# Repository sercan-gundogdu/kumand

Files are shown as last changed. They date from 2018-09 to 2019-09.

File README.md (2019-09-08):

# kumand [discontinued*]
Kumand is a low-power user-configurable remote controller device for personal computers, working on WLAN, allowing to manipulate every single media tool that has functionality to operate with keyboard shortcuts/hotkeys by emulating keystrokes determined in selected profile.

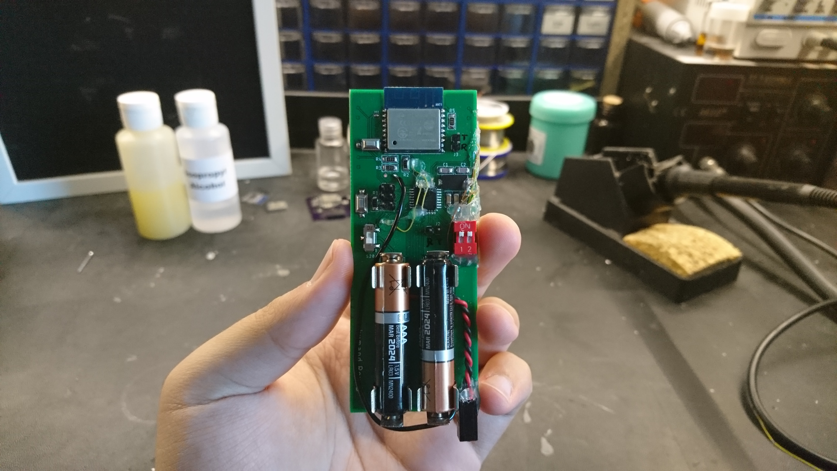
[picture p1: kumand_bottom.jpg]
kumand bottom

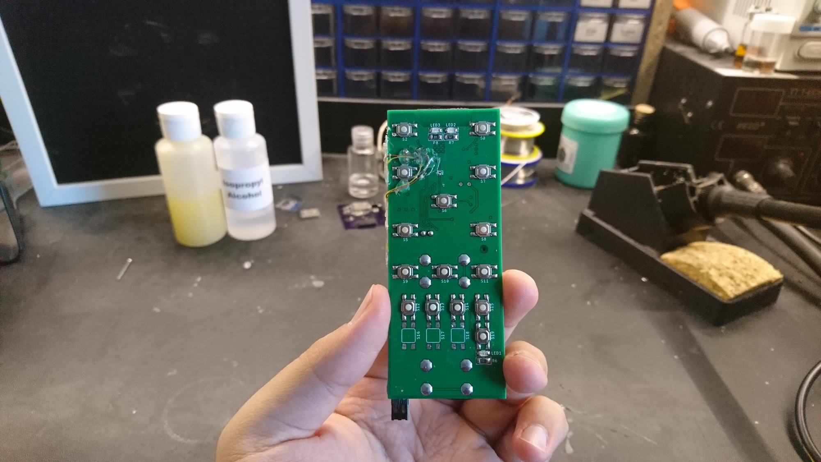
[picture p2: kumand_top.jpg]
kumand top


*The project is discontinued because the ESP8266 SoC does not meet the project's requirements in the aspect of power consumption and connectivity speed, it seems that ESP8266 has no proper sleep functionality to implement. The project will be redesigned with appropriate connectivity IC and MCU.

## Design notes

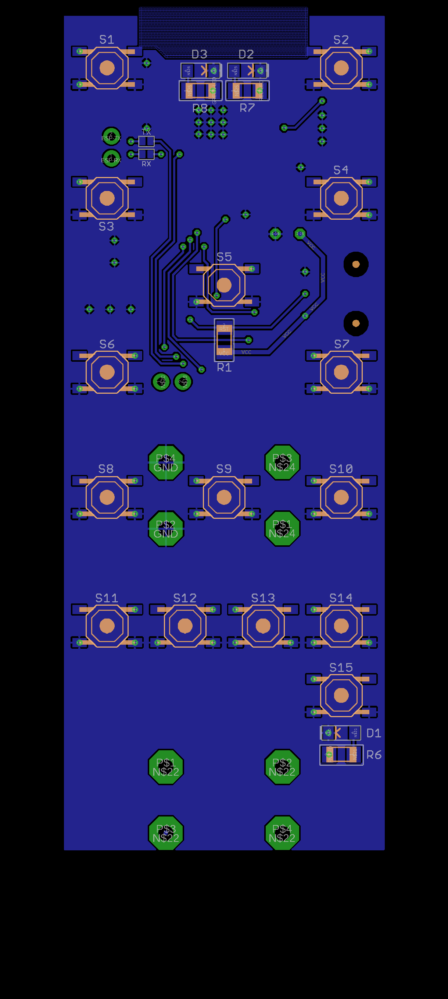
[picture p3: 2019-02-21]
source/hardware/pcb/bottom.png

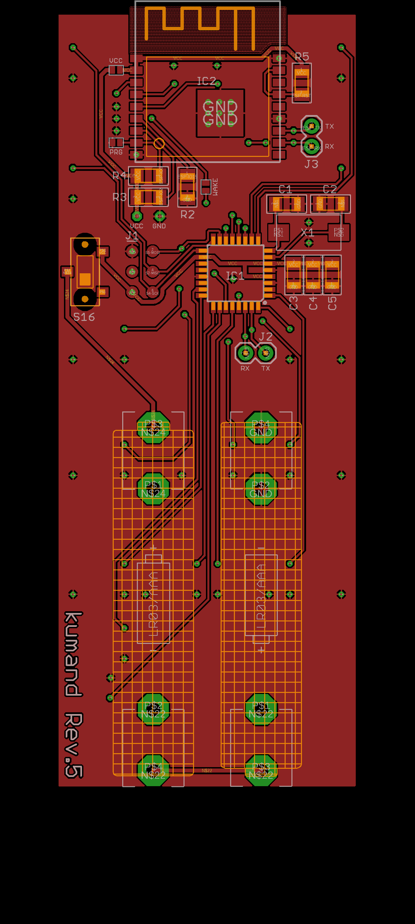
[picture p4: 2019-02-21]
source/hardware/pcb/top.png

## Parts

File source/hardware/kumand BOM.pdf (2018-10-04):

# | Designator | Manufacturer | Manufacturer PN | Value | Parametrics | Package | Layer

1 IC1 | Microchip Technology | ATMEGA328P-AUR | 1 | - | | TQFP | SMD | TOP
2 IC2 | Espressif Systems | ESP-WROOM-02 | 1 | - | | - | SMD | TOP
3 X1 | NDK America, Inc. | NX8045GB | 1 | 7.3728 MHz | | 8045[3117] | SMD | TOP
4 R1:R5 | Panasonic Electronic Components | ERJ-P08J103V | 5 | 10k Ohms | -55°C ~ +155°C, ±5%, 0.667W, 2/3W | | SMD | TOP
5 R6 | Panasonic Electronic Components | ERJ-8GEYJ101V | 1 | 100 Ohms | -55°C ~ +155°C, ±5%, 0.25W, 1/4W | | SMD | BOTTOM
6 R7 | Panasonic Electronic Components | ERJ-8GEYJ221V | 1 | 220 Ohms | -55°C ~ +155°C, ±5%, 0.25W, 1/4W | | SMD | BOTTOM
7 R8 | Panasonic Electronic Components | ERJ-8GEYJ561V | 1 | 480 Ohms | -55°C ~ +155°C, ±5%, 0.25W, 1/4W | | SMD | BOTTOM
8 C1,C2 | Samsung Electro-Mechanics | CL31C100DBCNNNC | 2 | 10pF | -55°C ~ 125°C, ±0.5pF, 50V, X7R | 3216[1206] | SMD | TOP
9 C3 | Samsung Electro-Mechanics | CL31B103KBCNNNC | 1 10nF(10000pF) | -55°C ~ 125°C , ±10%, 50V, X7R | 3216[1206] | SMD | TOP
10 C4 | Samsung Electro-Mechanics | CL31B104KBPWPNE | 1 0.1uF (100nf) | -55°C ~ 125°C , ±10%, 50V, X7R, AEC-Q200 | 3216[1206] | SMD | TOP
11 C5 | Samsung Electro-Mechanics | CL31B105KBHWPNE | 1 | 1uf | -55°C ~ 125°C , ±10%, 50V, X7R, AEC-Q200 | 3216[1206] | SMD | TOP
12 D1 | Lite-On Inc. | LTST-C150AKT | 1 | Amber | 2.1V, 10mA, 6mcd | 3216[1206] | SMD | BOTTOM
13 D2 | Lite-On Inc. | LTST-C150EKT | 1 | Red | 2V, 10mA, 6mcd | 3216[1206] | SMD | BOTTOM
14 D3 | Lite-On Inc. | LTST-C150GKT | 1 | Green | 2.1V, 10mA, 6mcd | 3216[1206] | SMD | BOTTOM
15 S1:S15 | C&K | PTS525 SM15 SMTR2 LFS | 15 | - | 0.02A, 15V, 160GF | - | SMD | BOTTOM
16 S16 | Nidec Copal Electronics | CL-SB-12B-02T | 1 | - | -40°C ~ 85°C, 200mA, 12V, 153GF | - | SMD | TOP
17 BATT-HOLDER | MPD (Memory Protection Devices) | BK-82-ND | 4 | LR03/AAA | | - | TH | T/B

Qty/
Unit

MNT
Type

-40°C ~ +80°C, 1.8V ~ 5.5V, 20 MHz 32KB Flash, 2048 Bytes, 23 IO -40°C ~ +85°C, 2.7V ~ 3.6V, 2MB Flash, <50KB SRAM
-10°C ~ +70°C, 8pF, ±30ppm
3216[1206]
3216[1206]
3216[1206]
3216[1206]

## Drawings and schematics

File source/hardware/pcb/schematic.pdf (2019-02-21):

A

A

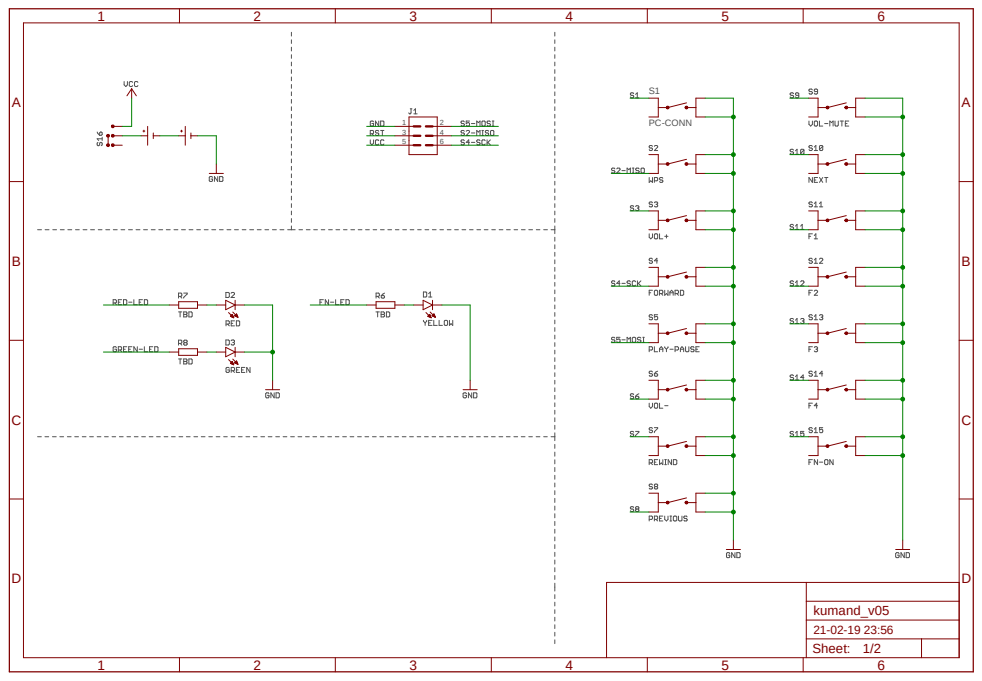
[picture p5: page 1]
PC-CONN; kumand_v05; 21-02-19 23:56 Sheet: 1/2

Sheet: 2/2 ABCD | 1 | 2 | 3 | 4 | 5 | 6 | ABCD 1 | 2 | 3 | 4 | 5 | 6

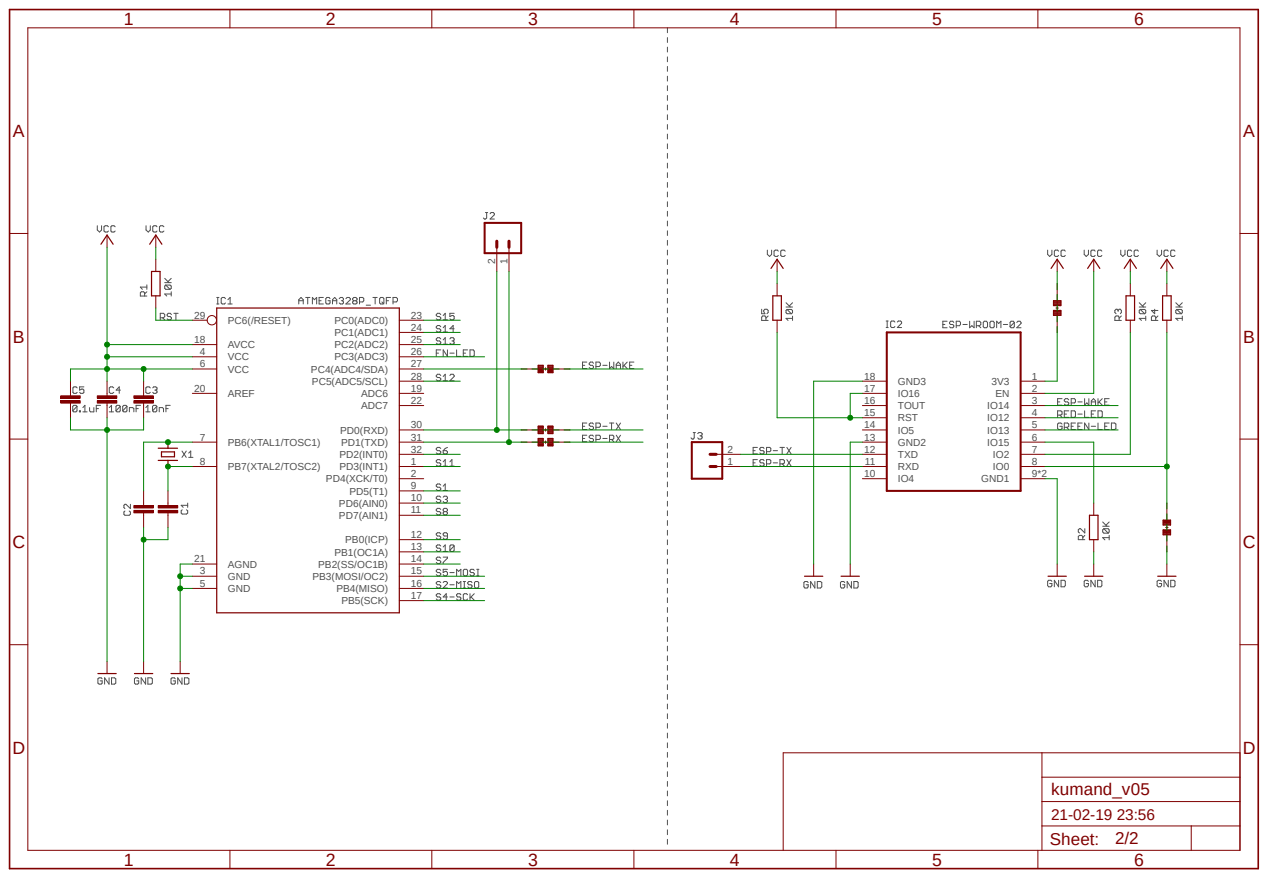
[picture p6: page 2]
PB5(SCK); PB7(XTAL2/TOSC2); PB6(XTAL1/TOSC1); GND; VCC; AGND 21; AREF 20; AVCC 18; PB4(MISO); 16 PB3(MOSI/OC2); 13 PB0(ICP); PD7(AIN1); 11 PD6(AIN0); PD4(XCK/T0); PD3(INT1); PD2(INT0); 32 PD1(TXD); 31 PD0(RXD); ADC7; 22 ADC6; 19 PC5(ADC5/SCL); 28 PC4(ADC4/SDA); 27 PC3(ADC3); 26 PC2(ADC2); 25 PC1(ADC1); 24 PC0(ADC0); 23 PC6(/RESET) 29; GND3 18; IO5 14 GND2 13 TXD 12 RXD 11; GND1; kumand_v05

IO16 17 | 2
TOUT 16 RST 15 | 3 4 5 6

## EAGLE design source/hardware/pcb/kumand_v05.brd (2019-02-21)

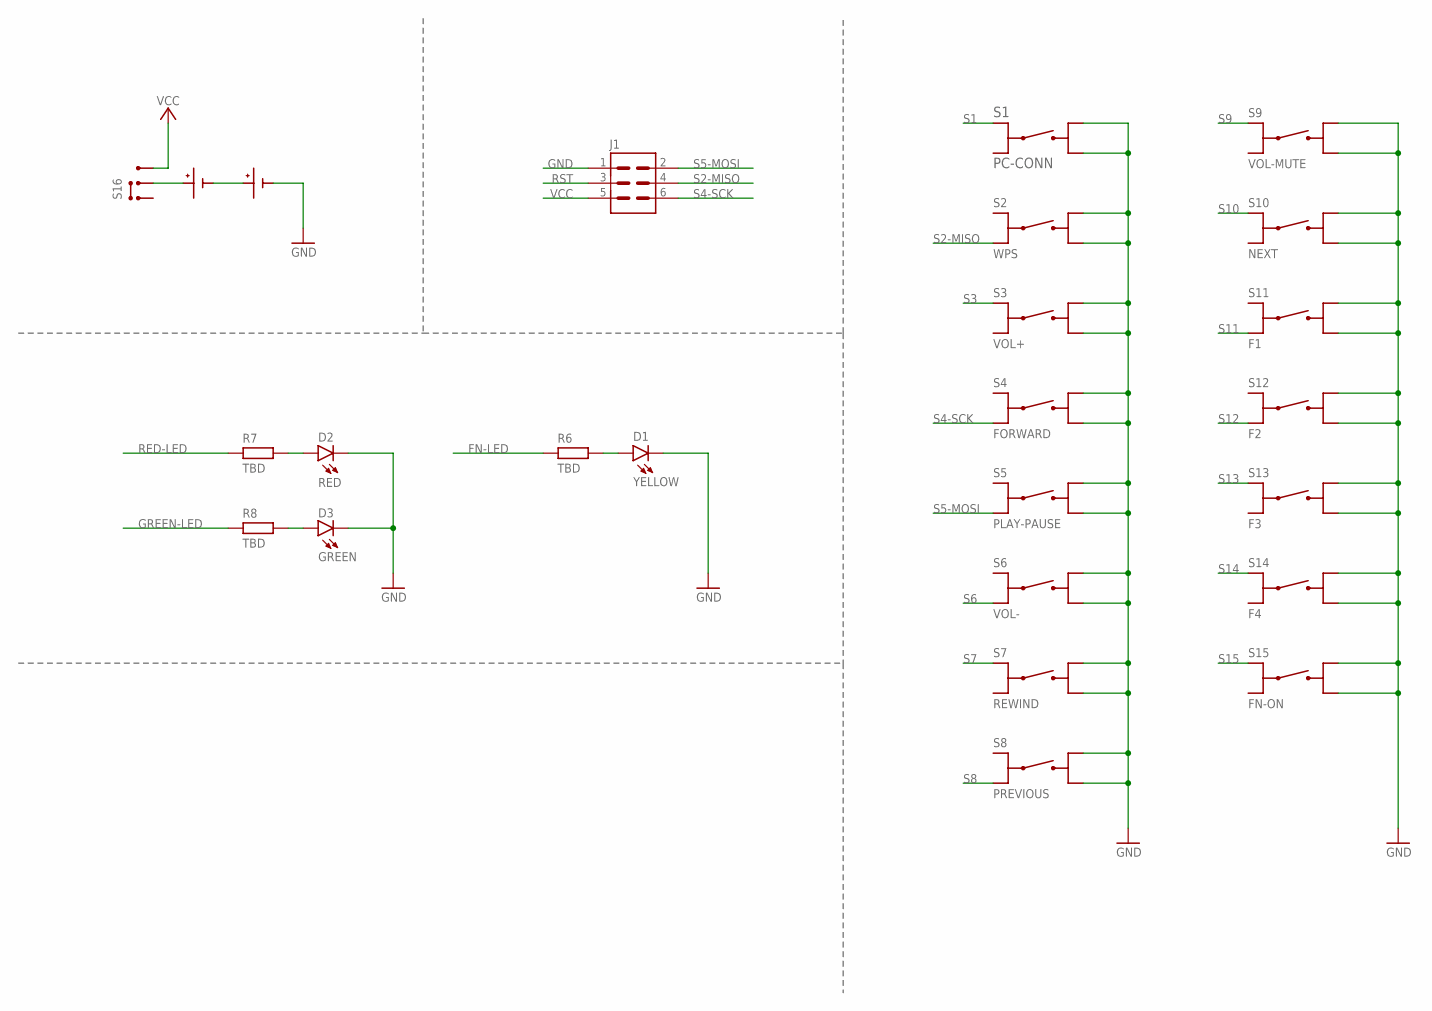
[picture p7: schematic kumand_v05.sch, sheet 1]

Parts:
D1: YELLOW; LED-1206
D2: RED; LED-1206
D3: GREEN; LED-1206
J1: 3X2-SMD-DOT
R6, R7, R8: TBD; R1206
S1: PC-CONN; PTS525
S2: WPS; PTS525
S3: VOL+; PTS525
S4: FORWARD; PTS525
S5: PLAY-PAUSE; PTS525
S6: VOL-; PTS525
S7: REWIND; PTS525
S8: PREVIOUS; PTS525
S9: VOL-MUTE; PTS525
S10: NEXT; PTS525
S11: F1; PTS525
S12: F2; PTS525
S13: F3; PTS525
S14: F4; PTS525
S15: FN-ON; PTS525
S16: CL-SB-12B-02T; CL-SB-12B-02T-PACKAGE
U$4, U$5: BK-82-DEVICE; BK-82-PACKAGE

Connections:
FN-LED: R6.2; also elsewhere on the board
GND: D1.C, D2.C, D3.C, J1.1, S1.3, S1.4, S2.3, S2.4, S3.3, S3.4, S4.3, S4.4, S5.3, S5.4, S6.3, S6.4, S7.3, S7.4, S8.3, S8.4, S9.3, S9.4, S10.3, S10.4, S11.3, S11.4, S12.3, S12.4, S13.3, S13.4, S14.3, S14.4, S15.3, S15.4, U$5.P$2, U$5.P$4; also elsewhere on the board
GREEN-LED: R8.2; also elsewhere on the board
unnamed: D1.A, R6.1
unnamed: U$4.P$2, U$4.P$4, U$5.P$1, U$5.P$3
unnamed: S16.P$2, U$4.P$1, U$4.P$3
unnamed: D2.A, R7.1
unnamed: D3.A, R8.1
RED-LED: R7.2; also elsewhere on the board
RST: J1.3; also elsewhere on the board
S1: S1.1; also elsewhere on the board
S2-MISO: J1.4, S2.2; also elsewhere on the board
S3: S3.1; also elsewhere on the board
S4-SCK: J1.6, S4.2; also elsewhere on the board
S5-MOSI: J1.2, S5.2; also elsewhere on the board
S6: S6.2; also elsewhere on the board
S7: S7.1; also elsewhere on the board
S8: S8.2; also elsewhere on the board
S9: S9.1; also elsewhere on the board
S10: S10.1; also elsewhere on the board
S11: S11.2; also elsewhere on the board
S12: S12.2; also elsewhere on the board
S13: S13.1; also elsewhere on the board
S14: S14.1; also elsewhere on the board
S15: S15.1; also elsewhere on the board
VCC: J1.5, S16.P$3; also elsewhere on the board

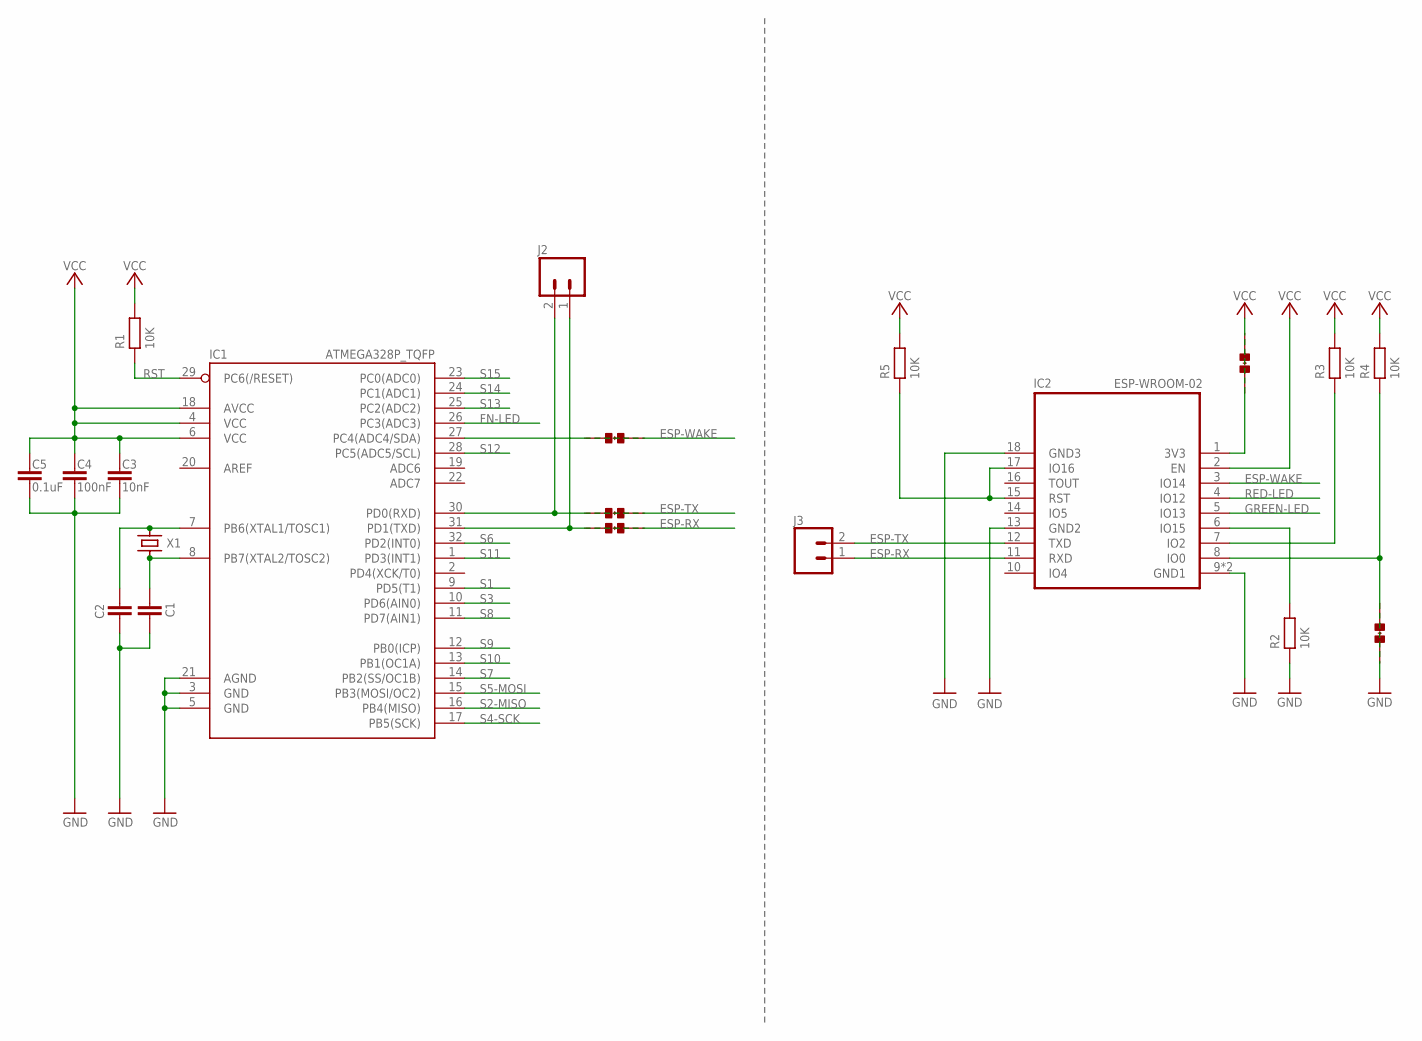
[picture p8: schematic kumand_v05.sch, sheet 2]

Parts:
C1, C2: C-EUC1206; C1206
C3: 10nF; C1206
C4: 100nF; C1206
C5: 0.1uF; C1206
IC1: ATMEGA328P_TQFP; TQFP32-08
IC2: ESP-WROOM-02; FRONT-FACE
J2, J3: CONN_02; 1X02
PRG: SOLDER-JUMPER; SOLDER-JUMPER-PACKAGE
R1, R2, R3, R4, R5: 10K; R1206
RX: SOLDER-JUMPER; SOLDER-JUMPER-PACKAGE
TX: SOLDER-JUMPER; SOLDER-JUMPER-PACKAGE
VCC: SOLDER-JUMPER; SOLDER-JUMPER-PACKAGE
WAKE: SOLDER-JUMPER; SOLDER-JUMPER-PACKAGE
X1: NX8045-CRYSTAL; NX8045

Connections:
ESP-IO0: IC2.8 (IO0), PRG.1, R4.1
ESP-IO2: IC2.7 (IO2), R3.1
ESP-IO15: IC2.6 (IO15), R2.1
ESP-RST: IC2.15 (RST), IC2.17 (IO16), R5.2
ESP-RX: IC2.11 (RXD), J3.1, RX.2
ESP-TX: IC2.12 (TXD), J3.2, TX.2
ESP-WAKE: IC2.3 (IO14), WAKE.2
FN-LED: IC1.26 (PC3(ADC3)); also elsewhere on the board
GND: C1.1, C2.1, C3.1, C4.1, C5.1, IC1.3 (GND), IC1.5 (GND), IC1.21 (AGND), IC2.9 (GND1), IC2.13 (GND2), IC2.18 (GND3), IC2.GND (GND1), PRG.2, R2.2; also elsewhere on the board
GREEN-LED: IC2.5 (IO13); also elsewhere on the board
unnamed: C1.2, IC1.8 (PB7(XTAL2/TOSC2)), X1.P$1
unnamed: IC1.27 (PC4(ADC4/SDA)), WAKE.1
unnamed: C2.2, IC1.7 (PB6(XTAL1/TOSC1)), X1.P$2
unnamed: IC1.30 (PD0(RXD)), J2.2, TX.1
unnamed: IC1.31 (PD1(TXD)), J2.1, RX.1
RED-LED: IC2.4 (IO12); also elsewhere on the board
RST: IC1.29 (PC6(/RESET)), R1.2; also elsewhere on the board
S1: IC1.9 (PD5(T1)); also elsewhere on the board
S2-MISO: IC1.16 (PB4(MISO)); also elsewhere on the board
S3: IC1.10 (PD6(AIN0)); also elsewhere on the board
S4-SCK: IC1.17 (PB5(SCK)); also elsewhere on the board
S5-MOSI: IC1.15 (PB3(MOSI/OC2)); also elsewhere on the board
S6: IC1.32 (PD2(INT0)); also elsewhere on the board
S7: IC1.14 (PB2(SS/OC1B)); also elsewhere on the board
S8: IC1.11 (PD7(AIN1)); also elsewhere on the board
S9: IC1.12 (PB0(ICP)); also elsewhere on the board
S10: IC1.13 (PB1(OC1A)); also elsewhere on the board
S11: IC1.1 (PD3(INT1)); also elsewhere on the board
S12: IC1.28 (PC5(ADC5/SCL)); also elsewhere on the board
S13: IC1.25 (PC2(ADC2)); also elsewhere on the board
S14: IC1.24 (PC1(ADC1)); also elsewhere on the board
S15: IC1.23 (PC0(ADC0)); also elsewhere on the board
VCC: C3.2, C4.2, C5.2, IC1.4 (VCC), IC1.6 (VCC), IC1.18 (AVCC), IC2.1 (3V3), IC2.2 (EN), R1.1, R3.2, R4.2, R5.1, VCC.1, VCC.2; also elsewhere on the board

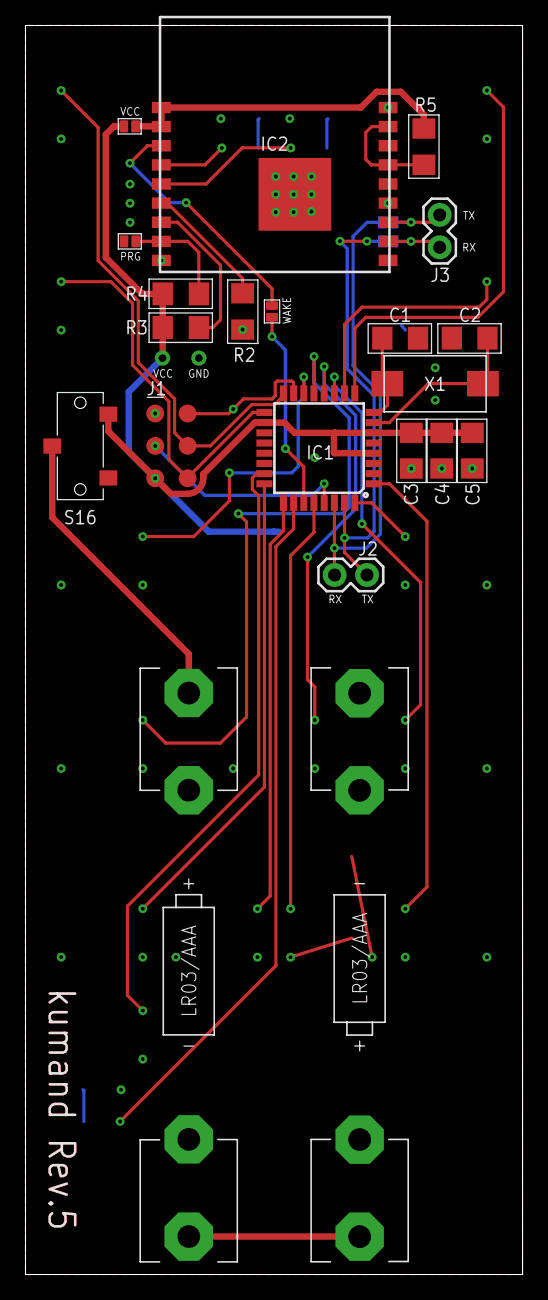
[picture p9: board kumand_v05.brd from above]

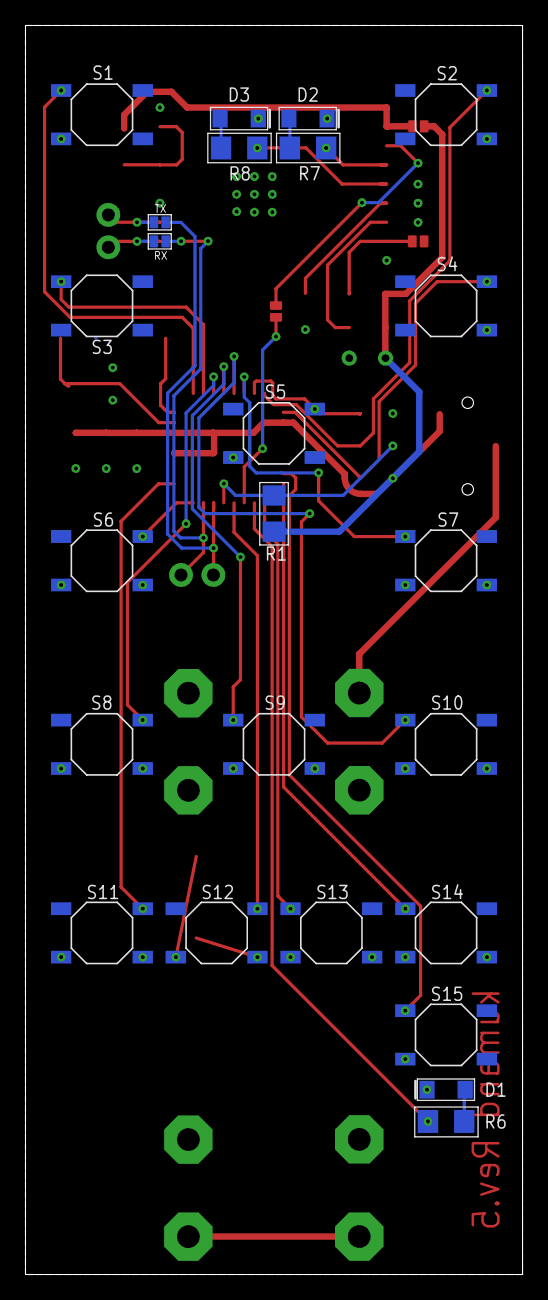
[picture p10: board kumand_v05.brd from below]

Board: 2 copper layers, 39.0 x 98.0 mm, 45 parts (24 on the bottom side), 38 nets.

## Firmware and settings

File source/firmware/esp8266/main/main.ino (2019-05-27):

// ----------------------------------------------------------------------------
//
//
// ----------------------------------------------------------------------------
#ifdef __cplusplus
  #include <ESP8266WiFi.h>
  extern "C" {
#endif

// ----------------------------------------------------------------------------
#include "main.h"

ADC_MODE(ADC_VCC);

// ----------------------------------------------------------------------------
void setup(){
  Serial.begin(115200);
  netctl_init();
  ioctl_init();
  ioctl_led_blink_pattern_1(IO_PIN_LED_GREEN, 3000);
  //wifi_fpm_set_sleep_type(LIGHT_SLEEP_T);
  Serial.write((byte)true);        
}

// ----------------------------------------------------------------------------
void loop(){
  uint8_t l_sleep_flag = pwrctl_sleep_flag_get();
  if(l_sleep_flag == 1){
    netctl_wifi_reconnect();
    pwrctl_sleep_flag_clear();
  }
  cmdctl_loop();
}

#ifdef __cplusplus
  }
#endif

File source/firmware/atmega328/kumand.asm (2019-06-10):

//-----------------------------------------------------------------------------
//
//
//-----------------------------------------------------------------------------
.include "m328pdef.inc"

//-----------------------------------------------------------------------------
.dseg

// Allocate 32 bytes of memory on SRAM for UART Transmit.
UART_TRANSMIT_BUFFER: .byte 32
// Allocate 32 bytes of memory on SRAM for UART Receive.
UART_RECEIVE_BUFFER:  .byte 32

//-----------------------------------------------------------------------------
.cseg

.org 0x0000 rjmp RESET // Reset Handler
//.org 0x0002 rjmp INT0 // IRQ0
//.org 0x0004 rjmp INT1 // IRQ1
//.org 0x0006 rjmp PCINT0 // PCINT0
//.org 0x0008 rjmp PCINT1 // PCINT1
//.org 0x000A rjmp PCINT2 // PCINT2
//.org 0x000C rjmp WDT // Watchdog Timeout
//.org 0x000E rjmp TIM2_COMPA // Timer2 CompareA
//.org 0x0010 rjmp TIM2_COMPB // Timer2 CompareB
//.org 0x0012 rjmp TIM2_OVF // Timer2 Overflow
//.org 0x0014 rjmp TIM1_CAPT // Timer1 Capture
//.org 0x0016 rjmp TIM1_COMPA // Timer1 CompareA
//.org 0x0018 rjmp TIM1_COMPB // Timer1 CompareB
//.org 0x001A rjmp TIM1_OVF // Timer1 Overflow
//.org 0x001C rjmp TIM0_COMPA // Timer0 CompareA
//.org 0x001E rjmp TIM0_COMPB // Timer0 CompareB
//.org 0x0020 rjmp TIM0_OVF // Timer0 Overflow
//.org 0x0022 rjmp SPI_STC // SPI Transfer Complete
//.org 0x0024 rjmp UART_RXC // UART RX Complete
//.org 0x0026 rjmp UART_UDRE // UART UDR Empty
//.org 0x0028 rjmp UART_TXC // UART TX Complete
//.org 0x002A rjmp ADC // ADC Conversion Complete
//.org 0x002C rjmp EE_RDY // EEPROM Ready
//.org 0x002E rjmp ANA_COMP // Analog Comparator
//.org 0x0030 rjmp TWI // 2-wire Serial
//.org 0x0032 rjmp SPM_RDY // SPM Ready

.equ PORTB_MASK = 0b00111111
.equ PORTC_MASK = 0b00100111
.equ PORTD_MASK = 0b11101100

.equ GET_WLAN_STATUS = 0x02
.equ GET_PC_STATUS = 0x03
.equ SEND_KEY = 0x04
.equ SET_DESTINATION_IP = 0x05
.equ RUN_WPSPBC = 0x0A
.equ GET_DESTINATION_IP = 0x0B

//-----------------------------------------------------------------------------
.macro eepromWrite
  // Load the address of the string to be sent, to r16:r17
  ldi r17, high(@0)
  ldi r16, low(@0)

  // Push the address to stack and call EEPROM_Write function
  push r16
  push r17
  rcall EEPROM_Write
  pop r17
  pop r16

.endmacro

//-----------------------------------------------------------------------------
.macro eepromRead
  // Load the address of the string to be read, to r16:r17
  ldi r17, high(@0)
  ldi r16, low(@0)

  // Push the address to stack and call EEPROM_Read function
  push r16
  push r17
  rcall EEPROM_Read
  pop r17
  pop r16

.endmacro

//-----------------------------------------------------------------------------
RESET:
  // Initialize Stack Pointer
  ldi r16, high(RAMEND)
  out SPH, r16 
  ldi r16, low(RAMEND) 
  out SPL, r16 

  // Initialize GPIO
  rcall GPIO_Init

  // Initialize UART
  rcall UART_Init

  // Set r8 to 0xFF as a refrence
  ldi r16, 0xFF
  mov r8, r16
  clr r16
  
  // Ignore incoming garbage and wait for the response 0x01
  rcall UART_Receive_Byte
  cpi r16, 0x01
  brne PC-2

  // Send destination IP
  rcall IP_SYNC

  rjmp MAIN

//-----------------------------------------------------------------------------
GPIO_Init:
  // Set PORTB pins 0, 1, 2, 3, 4, 5 as INPUT
  ldi r16, (0<<PB0) | (0<<PB1) | (0<<PB2) | (0<<PB3) | (0<<PB4) | (0<<PB5)
  out DDRB, r16
  
  // Internal pull-up for PORTB pins 0, 1, 2, 3, 4, 5
  ldi r16, (1<<PB0) | (1<<PB1) | (1<<PB2) | (1<<PB3) | (1<<PB4) | (1<<PB5)
  out PORTB, r16
  
  // Set PORTC pins 0, 1, 2, 5 as INPUT
  //  3, 4 as OUTPUT
  ldi r16, (0<<PC0) | (0<<PC1) | (0<<PC2) | (1<<PC3) | (1<<PC4) | (0<<PC5)
  out DDRC, r16
  
  // Internal pull-up for PORTC pins 0, 1, 2, 5
  //  Pins 3,4 driven low
  ldi r16, (1<<PC0) | (1<<PC1) | (1<<PC2) | (0<<PC3) | (0<<PC4) | (1<<PC5) 
  out PORTC, r16
  
  // Set PORTD pins 2, 3, 5, 6, 7 as INPUT
  ldi r16, (0<<PD2) | (0<<PD3) | (0<<PD5) | (0<<PD6) | (0<<PD7)
  out DDRD, r16
  
  // Internal pull-up for PORTD pins 2, 3, 4, 5, 6, 7
  ldi r16, (1<<PD2) | (1<<PD3) | (1<<PD5) | (1<<PD6) | (1<<PD7)
  out PORTD, r16
  
  ret

//-----------------------------------------------------------------------------
UART_Init:
  // UBRR0 = 0x003 for 115.2K baudrate at 7.3728MHz.
  // Load 0x003 to UBRR0(USART Baud Rate Register)
  ldi r17, 0x0
  ldi r16, 0x03
  sts UBRR0H, r17
  sts UBRR0L, r16
  
  // Enable Receiver and Transmitter in -
  // UCSR0B(USART Control and Status Register 0B)
  // Normal port operations overriden!
  ldi r16, (1<<RXEN0) | (1<<TXEN0) 
  sts UCSR0B, r16
  
  // Set UCSR0C(USART Control and Status Register 0C) = 0x06
  // Frame format: 8 data bit, 1 stop bit, no parity.
  ldi r16, (0<<USBS0) | (3<<UCSZ00)
  sts UCSR0C, r16
  
  ret

//-----------------------------------------------------------------------------
UART_Transmit_Byte:
  // This function transmits a single byte stored in r16 over UART 
  // Wait for UDRE0 (USART Data Register Empty) bit is set in -
  // USART Control and Status Register
  lds r17, UCSR0A
  sbrs r17, UDRE0
  rjmp UART_Transmit_Byte
  
  // Load byte stored in r16 to buffer and send byte
  // Data will be sent and UDR0(USART I/O Data Register) will be cleared -
  // automatically after load into it
  sts UDR0, r16

UART_Transmit_Byte_Ret: 
  ret

//-----------------------------------------------------------------------------
UART_Transmit_Str:
  // The data being stored in buffer called UART_TRANSMIT_BUFFER will be sent
  // Load buffer address to register X
  ldi XH, high(UART_TRANSMIT_BUFFER)
  ldi XL, low(UART_TRANSMIT_BUFFER)

UART_Transmit_Str_Loop: 
  // Load data stored in buffer into r16 and transmit
  // Termination character is included.
  ld r16, X+
  rcall UART_Transmit_Byte

  // If data is not null-termination byte, continue transmitting
  cpi r16, '\0'
  brne UART_Transmit_Str_Loop

UART_Transmit_Str_Ret:  
  ret

//-----------------------------------------------------------------------------
UART_Receive_Byte:
  // This function receives a single byte over UART and store it in r16
  // Wait for RXC0 (USART Receive Complete) bit is set in -
  // USART Control and Status Register
  lds r17, UCSR0A
  sbrs r17, RXC0
  rjmp UART_Receive_Byte
  
  // Receive data and store it in register r16 
  // UDR0(USART I/O Data Register) will be cleared automatically after -
  // reading from it
  lds r16, UDR0
  
UART_Receive_Byte_Ret:  
  ret

//-----------------------------------------------------------------------------
UART_Receive_Str:
  // The received data will be stored in buffer called UART_RECEIVE_BUFFER -
  // allocated in SRAM.
  // Load buffer address to register X
  ldi XH, high(UART_RECEIVE_BUFFER)
  ldi XL, low(UART_RECEIVE_BUFFER)
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

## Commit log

2018-10-04 Adding Bills of Materials
2019-02-21 Some cosmetic touch to schematic
    [kumand_v05.brd, kumand_v05.sch]
2019-06-10 cosmetic touch on assembly file
2019-09-08 uploading photos of working boards

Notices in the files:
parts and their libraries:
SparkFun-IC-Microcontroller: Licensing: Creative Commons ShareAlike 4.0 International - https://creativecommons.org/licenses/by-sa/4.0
